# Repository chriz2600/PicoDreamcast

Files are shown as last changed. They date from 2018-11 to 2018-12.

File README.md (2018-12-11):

# PicoDreamcast

Small adapter board to easily hook up a PicoPSU to the Dreamcast

## Update

There was an issue, that the PicoPSU was not turning completely off, when PS_ON# was released, when no load is present on the 12V rail. The fix is to add a resistor (>10k) between 12V and GND.

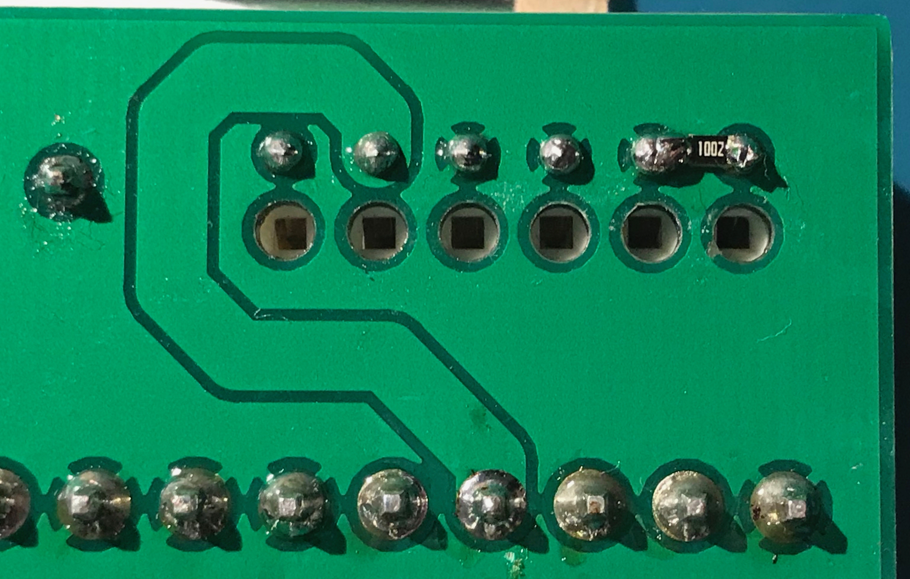
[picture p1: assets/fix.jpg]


The updated PCB includes this resistor.

## 

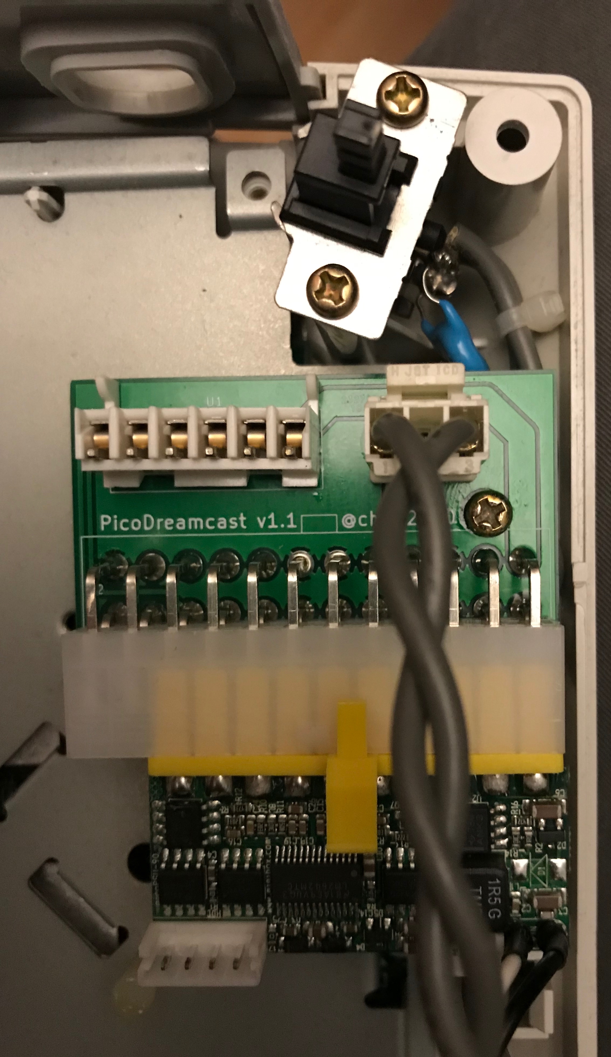
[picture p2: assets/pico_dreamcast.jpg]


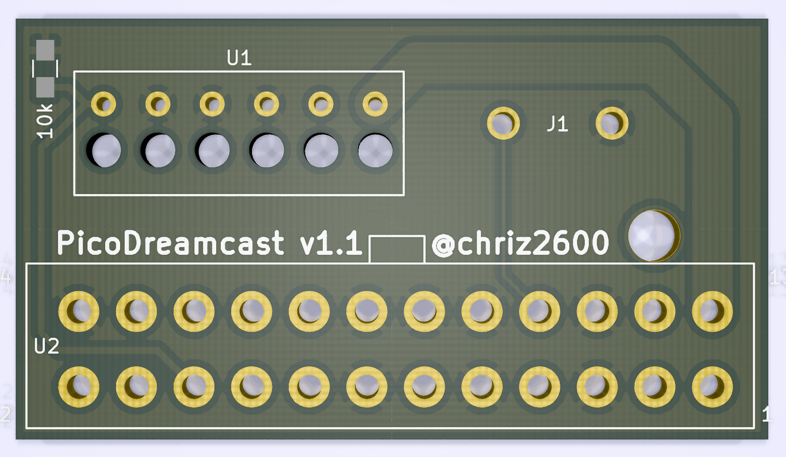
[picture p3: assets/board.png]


- **BOM**

    - **U1**: [Dreamcast power connector](https://www.digikey.com/product-detail/en/molex-connector-corporation/09-48-3064/WM13523-ND/863357)

    - **U2**: [ATX connector](https://www.aliexpress.com/item/5pcs-Motherboard-ATX-4-2-mm-24-pin-Male-Header-Pins-24-P-Mainboard-CPU-Power/32854035770.html)

    - **J1**: [Dreamcast power switch connector](https://www.digikey.com/product-detail/en/te-connectivity-amp-connectors/1-1123724-2/A106608-ND/686935)

    - [**PicoPSU**](http://www.mini-box.com/picoPSU-90)

    - [**Power supply**](https://www.amazon.de/gp/product/B00NWH1FTS/)

        *Any 12V 60+W power supply will do the job*

- **Gerber files**

    [`gerber.zip`](https://github.com/chriz2600/PicoDreamcast/blob/master/gerber.zip)

- **Power connector replacement**

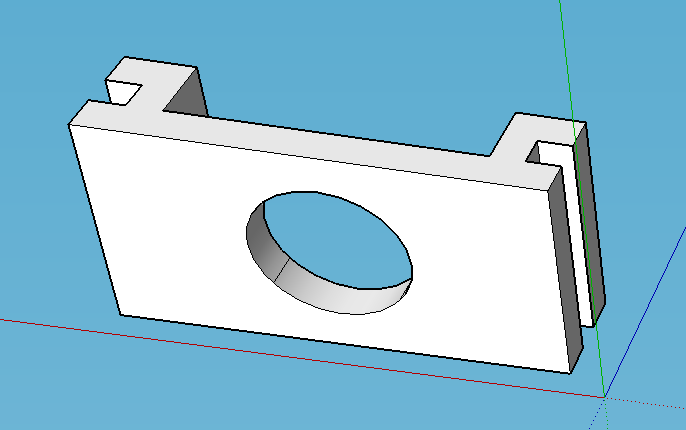
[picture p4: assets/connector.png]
Power connector replacement
    

    [SketchUp files](https://github.com/chriz2600/PicoDreamcast/tree/master/3dprinted)

##### Reference: [ATX12V Power Supply Design Guide](http://www.ieca-inc.com/images/ATX12V_PSDG2.0_Ratified.pdf)

#### 3.3.2 PS_ON#

PS_ON# is an active-low, TTL-compatible signal that allows a motherboard to remotely
control the power supply in conjunction with features such as soft on/off, Wake on LAN*,
or wake-on-modem. When PS_ON# is pulled to TTL low, the power supply should turn on
the five main DC output rails: +12VDC, +5VDC, +3.3VDC, -5VDC, and -12VDC. When
PS_ON# is pulled to TTL high or open-circuited, the DC output rails should not deliver
current and should be held at zero potential with respect to ground. PS_ON# has no effect
on the +5VSB output, which is always enabled whenever the AC power is present. Table
14 lists PS_ON# signal characteristics.

The power supply shall provide an internal pull-up to TTL high. The power supply shall
also provide de-bounce circuitry on PS_ON# to prevent it from oscillating on/off at startup
when activated by a mechanical switch. The DC output enable circuitry must be SELVcompliant.

The power supply shall not latch into a shutdown state when PS_ON# is driven active by
pulses between 10ms to 100ms during the decay of the power rails. 

---

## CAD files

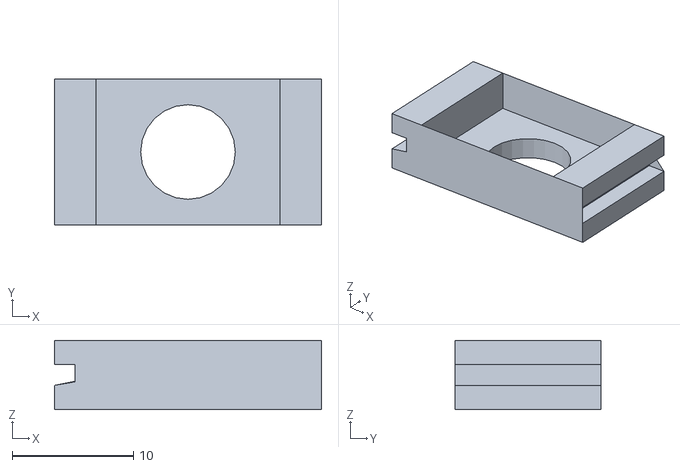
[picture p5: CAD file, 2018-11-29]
3dprinted/pico_dreamcast.obj
22.0 x 12.0 x 5.70

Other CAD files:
3dprinted/pico_dreamcast.skp

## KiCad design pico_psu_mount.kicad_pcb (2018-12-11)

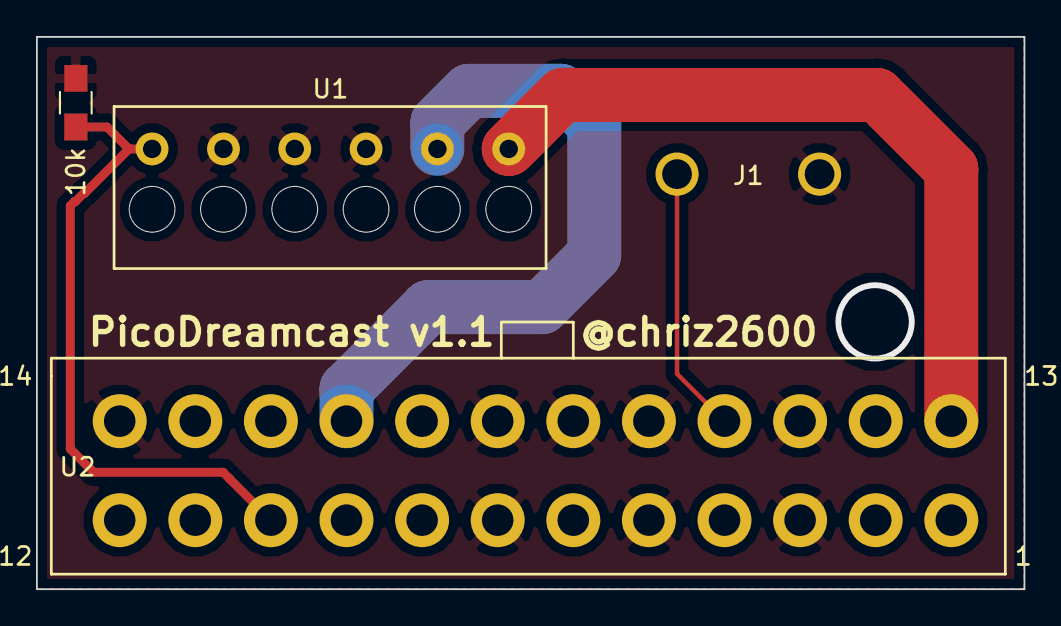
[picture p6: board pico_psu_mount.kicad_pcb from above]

Board: 2 copper layers, 54.9 x 30.7 mm, 4 parts (0 on the bottom side), 5 nets.

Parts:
10k: R; R_0805_HandSoldering
J1: Conn_01x02; AMP-1-1123724-2
U1: DreamcastPower
U2: atx_24pin; ATX_24_pin

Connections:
/3.3V: U1.1, U2.13
/5V: U1.2, U2.21
/12V: 10k.1, U1.6, U2.10
/nPSon: J1.1, U2.16
GND: 10k.2, J1.2, U1.3, U1.4, U1.5, U2.3, U2.5, U2.7, U2.15, U2.17, U2.18, U2.19, U2.24

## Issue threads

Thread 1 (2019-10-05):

PicoPSU remains on when switch is off, and Dreamcast Fan keeps running.

StrikerMan780, 2019-10-05:
It seems even on the 1.1 boards, the PicoPSU remains on when the power switch is off, and it keeps running my Dreamcast's fan. I don't even think it always did this either, only recently started to happen. Any idea what might be going on? Maybe something isn't turning off the 5v rail?

chriz2600, 2019-10-05:
Regarding your question asked on the commit page:

> Does the resistor need to be soldered onto 1.1 boards? Or is this only for 1.0? I ask because my Dreamcast's fan runs while the system is off for some reason.

Yes, the resistor is needed to turn the system off properly. Version 1.1 just adds pads on top of the PCB for a resistor. If you have the resistor installed, make sure you can measure it's value between 12V and GND (disconnect board from Dreamcast and PicoPSU).

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

StrikerMan780, 2019-10-06:
This is what mine looks like: 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

It looks like there's something there, but the thing still doesn't turn off properly. I soldered a 47k resistor between the two directly before to see if it helps, but I didn't have any luck.

chriz2600, 2019-10-07:
Ok, so when you remove the board from the console and unplug the PicoPSU, what do you measure between 12V and GND? 47k ohm may be too high, haven't tested that myself yet. You're saying you have a HDD connected to the PicoPSU, I assume it's connected to the extra header on the PicoPSU. Does it make any difference, if you leave the connector disconnected?

StrikerMan780, 2019-10-09:
I don't have the tools to measure the current between them. I don't have an HDD connected. I did, but only temporarily as I needed a surrogate power supply to run a drive for a project. It was just using the included cable with the PicoPSU. That's no longer there, and there's no difference if it's present or not.

chriz2600, 2019-10-09:
Sorry, my mistake, I didn't asked specifically what to measure: It's not the current, it's the resistance I'm asking for, just to make sure there is no bad connection between the resistor and 12V/GND (if you don't have a multimeter, just ignore this).
Another question: Do you have a DCHDMI? If yes, is a HDMI cable connected? If yes, can you test without the HDMI cable plugged in?

StrikerMan780, 2019-10-13:
I don't have a multimeter, sorry. And no, it's a standard, unmodified VA1
Dreamcast.

On Wed, Oct 9, 2019, 7:21 PM Christof Harnischmacher <
notifications@github.com> wrote:

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

chriz2600, 2019-10-13:
At this point, I have to assume, that the resistor itself or the connection is open (the connection from the resistor to the 12V and/or Ground), because the symptom you are describing (5V rail remains active, when PS_ON# is high) is exactly what can be observed when no resistor is present on the 12V rail. Unfortunately, without tools to do any test, it's not possible to troubleshoot properly.
I think, best option is to ask the seller for a replacement.

StrikerMan780, 2019-12-03:
I've tried multiple times to solder new resistors onto it, both with the designated pads, and between the two pins directly. Nothing worked, and eventually the solder pads on the PicoDreamcast were ruined due to so many times re-doing this. I can only assume the PicoPSU was faulty.

Oh well, $120 down the drain. Shit.

Canuma, 2020-11-26:
I have the same problem unfortunately. I am fully modding my Dreamcast and have just installed DC Digital. Next was PicoPSU, now the Dreamcast would never turn off. I followed this thread and measured the Resisitor from the 1.1. design, has 10k as expected. I also checked the 12V/Gnd on the DC Connector, still 10k. I even moved the whole PicoDreamcast Setup into a stock DC, but no luck. I also tried with an attached harddrive, to the picopsu connector, made no difference. I am out of ideas now. Could the PSU somehow be broken? Or has something changend?  I have the PicoPSU-80 if it matters, ordered via Amazon, where at least on Dreamcast User successfully adapted the PSU to the Dreamcast, without the PicoDC though.

KnightNZ, 2021-08-10:
I just got a PicoPSU and PD, and am having much the same problem. Regardless of the state of the power switch, the Dreamcast is fully powered. Resistor is present and measures @ 10K.
I'm running a TerraOnion MODE, and the DC also has the DCHDMI installed, so could it be a load issue somewhere?

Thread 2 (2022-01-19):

Intermitantly power on/off jitter

mdmmarshall67, 2022-01-19:
Hello
I have made up this board and have a issue where sometimes the power seems to turn on and off flashing the power led on occasion .It seems to work mostly .I was wondering if you could point me i the right direction to fix this .I know you mention the issue or something like it in the readme but just not sure of a fix .Many thanx in advance

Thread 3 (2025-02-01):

Instead of molex?

thanius, 2025-02-01:
This is more of a feature request than an issue. Well, it's because of an issue. We have all experienced power issues when the motherboard pins oxidize. How about instead of having a molex spring connection, we have some sort of cable solution?
We could use a terminal block on the PSU board and then some sort of cable shoe mechanism to fasten these to the motherboard pins? Or even some sort of cable shoe that we can solder directly onto the pins after fitting them?

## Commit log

2018-11-29 added atx power supply reference on nPS_ON
2018-12-11 fixed: PicoPSU does not turns off properly, when no load is present on the 12V rail
    [pico_psu_mount-B.Cu.gbl, pico_psu_mount-B.Mask.gbs, pico_psu_mount-B.SilkS.gbo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]

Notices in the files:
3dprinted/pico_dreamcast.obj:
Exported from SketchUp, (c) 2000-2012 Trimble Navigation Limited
